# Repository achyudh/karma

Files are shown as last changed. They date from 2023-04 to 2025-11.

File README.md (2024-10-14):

# Karma

Karma is a 36-key wireless split ergonomic mechanical keyboard inspired by two very popular ergonomic keyboards: [Corne](https://github.com/foostan/crkbd) and [TOTEM](https://github.com/GEIGEIGEIST/TOTEM).

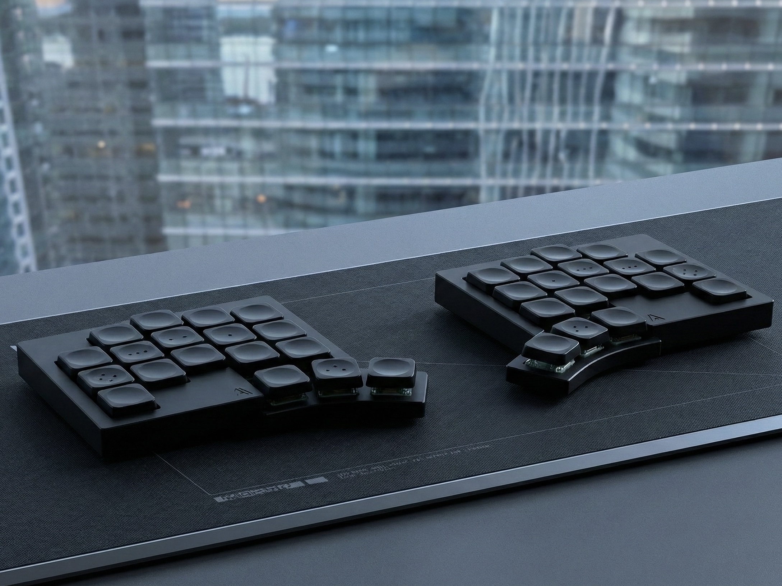
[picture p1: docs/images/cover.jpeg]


## Features

- **Ergonomic 36-key layout**: A compact layout with 3x5 column-staggered keys, plus 3 thumb keys for each side.
- **Wireless first**: Prioritizes a wireless split setup but can be used partially-wired by connecting the central side using USB-C.
- **Low-profile design**: Engineered for a sleek, low-profile build that allows your palms to rest comfortably on the table while typing. This is achieved through the use of Kailh Choc switches and recessed cutouts for hot-swap sockets, reducing the overall case height (similar to the TOTEM keyboard), and using 1mm EVA foam instead of rubber feet.
- **Exceptional battery life**: Has a battery life that is measured in weeks, not days.

### Firmware

The Karma keyboard supports the [ZMK](https://zmk.dev/) open-source firmware. You can find my ZMK configuration for this keyboard in [this repo](https://github.com/achyudh/karma-zmk).

## Build Guide

### Bill of Materials

To build the Karma keyboard, you'll need the following components:

| Part Name | Qty | Remarks |
| --- |:---:| --- |
| 2x SEEED XIAO BLE microcontrollers | 2 | |
| Kailh Choc V1 low-profile switches | 36 | Low-profile mechanical switches |
| Keycaps compatible with Kailh Choc V1 | 36 | MX-spaced keycaps are preferred for better fit |
| Hotswap sockets for Kailh Choc V1 | 36 | |
| SOD123 diodes | 36 | |
| JST PH 2-pin SMD Header | 2 | |
| 301230 LiPo Batteries | 2 | Only 1 required for partially wired build |
| 3D-printed case | 2 | |
| M2 screws (5mm length) | 8 | |
| M2 heat-set inserts (2mm height) | 8 | |
| Self-adhesive EVA foam (1mm) | - | A slimmer alternative to rubber feet |

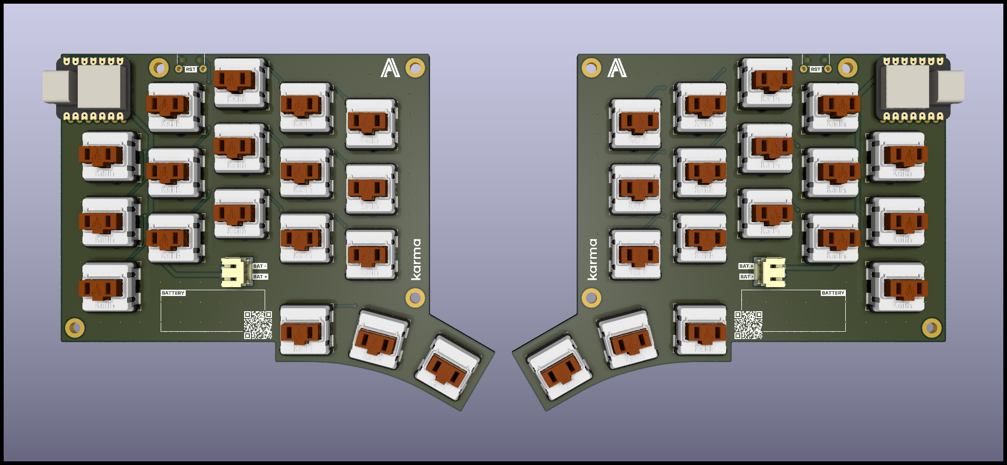
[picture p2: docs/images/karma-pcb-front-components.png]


### Assembly

**1. Order the Components**
- Zip up the gerber files for the [left side](./pcb-left/pcb-left-gerbers/) and the [right side](./pcb-right/pcb-right-gerbers/).
- Order the PCBs from a PCB prototype manufacturer like JLCPCB.
- 3D print the STL files for the case in [this repo](./enclosure/).
- All the other components are generic and can be found in Aliexpress.

**2. Solder the Diodes**
- Solder the SOD123 diodes to the top of the PCB, paying attention to the polarity.
- Apply solder to one pad, place the diode, and reflow the solder. Then solder the second pad.

**3. Install the Hotswap Sockets**
- Solder hotswap sockets in place by first securing one pad, then ensuring they are properly seated before soldering the second pad.

**4. Microcontroller Installation**
- Flash the firmware onto the SEEED XIAO BLE microcontrollers before soldering them to the PCB.
- Place the microcontroller in the designated spot and solder the pads, starting with the corners to secure it, then solder the rest.

**5. Connect the Batteries**
- Solder the JST PH 2-pin SMD Header to the PCB.
- Check the polarity of the battery with a multimeter and connect the batteries to the JST header such that the red wire is connected to the positive (+) pad and the black wire to the negative (-) pad on the PCB.

**6. Mount the Case**
- Insert M2 heat-set inserts into the screw holes in the 3D-printed case.
- Place the PCB inside the case, ensuring the microcontroller and battery fit snugly.
- Attach the two halves of the case using the M2 screws, securing them tightly.

**7. Install the Keycaps and Switches**
- Insert the Kailh Choc V1 switches into the hotswap sockets, ensuring they click into place.
- Attach your keycaps to the switches.

**8. Add EVA Foam**
- Cut and apply self-adhesive EVA foam to the bottom of the case for added grip and cushioning.

**9. Final steps**
- Once assembled, test the keyboard to ensure all switches and connections work.
- If necessary, adjust the [ZMK](https://zmk.dev/) firmware for your specific keymap.

Congratulations! You've completed your Karma keyboard build.

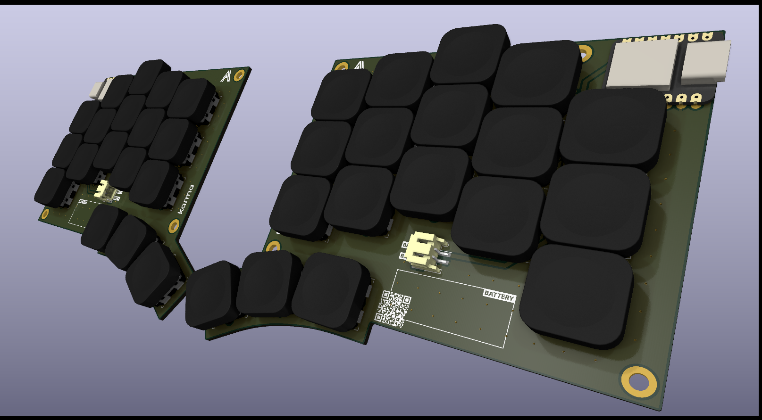
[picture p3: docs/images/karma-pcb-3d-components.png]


## License

This project is open-source and licensed under the CERN Open Hardware Licence Version 2 - Strongly Reciprocal License. See the [LICENSE](./LICENSE) file for details.

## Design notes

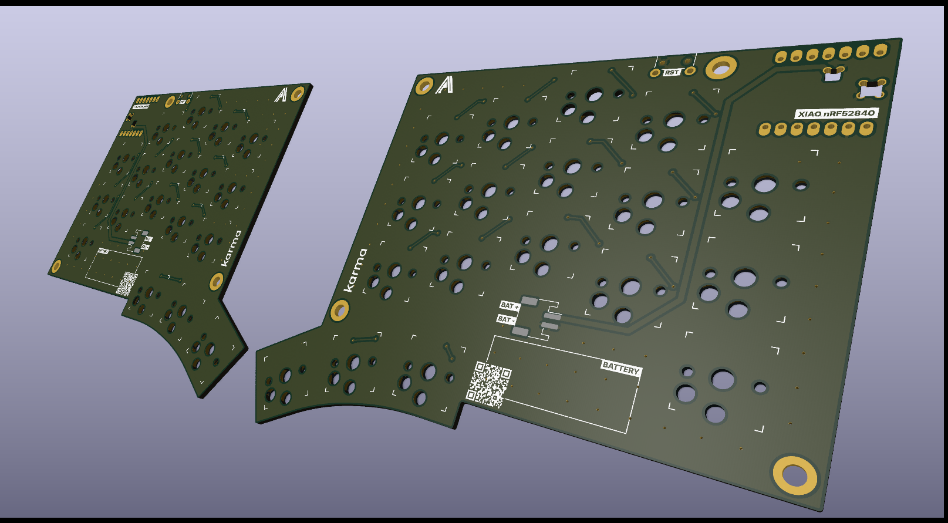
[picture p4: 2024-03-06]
docs/images/karma-pcb-3d.png

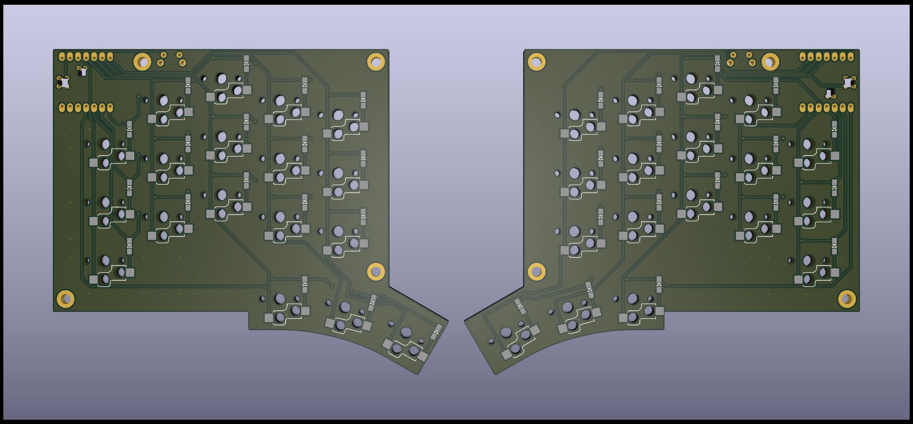
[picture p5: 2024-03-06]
docs/images/karma-pcb-back.png

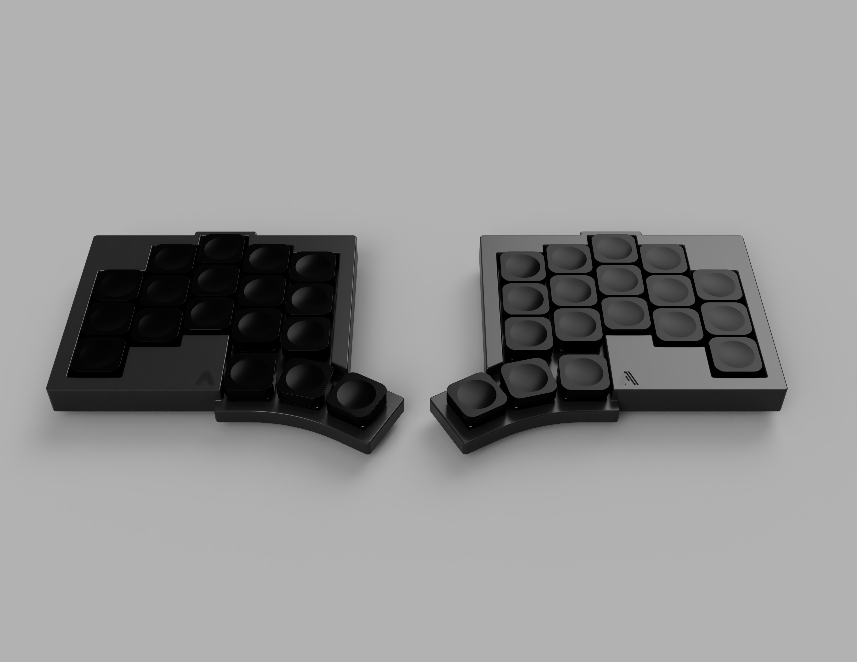
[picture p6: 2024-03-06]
docs/images/enclosure.png

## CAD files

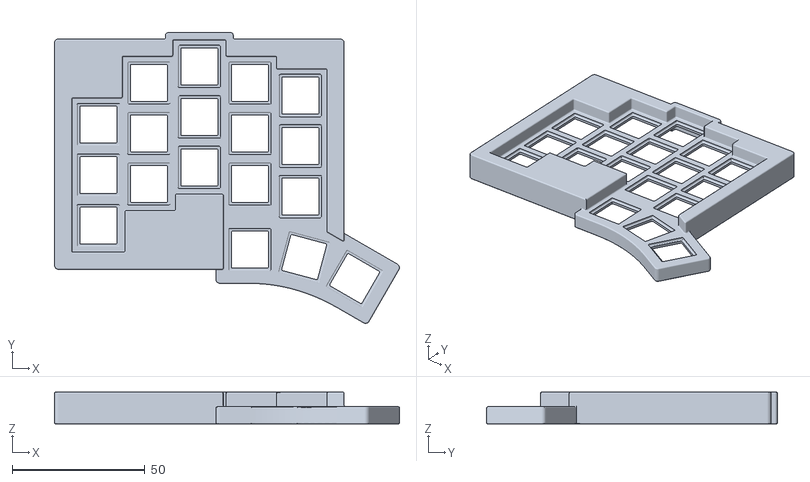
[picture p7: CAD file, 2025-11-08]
enclosure/top-left-no-logo.stl
129.8 x 109.4 x 12.0

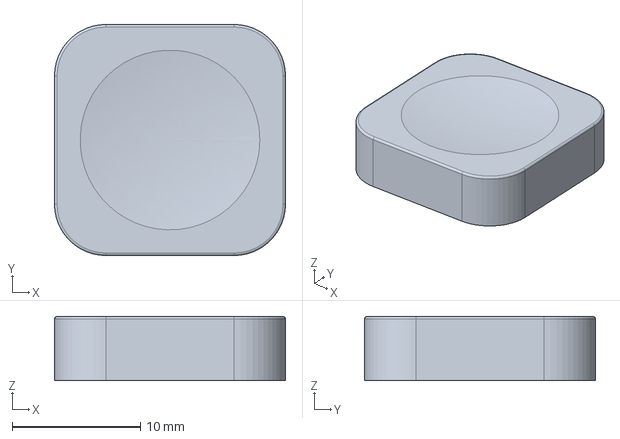
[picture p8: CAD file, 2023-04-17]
pcb-left/karmalib.step/Keycap.step
18.0 x 18.0 x 5.00 mm

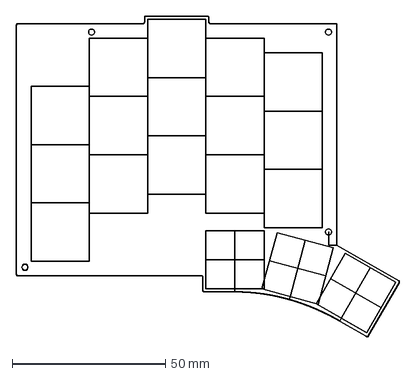
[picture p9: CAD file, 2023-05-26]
pcb-left/pcb-left-edge-cuts.dxf
124.9 x 104.5 mm

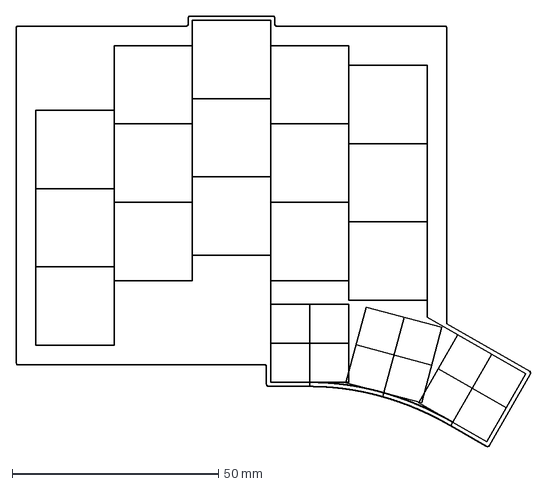
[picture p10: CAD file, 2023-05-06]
pcb-right/pcb-right-edge-cuts.dxf
124.9 x 104.5 mm

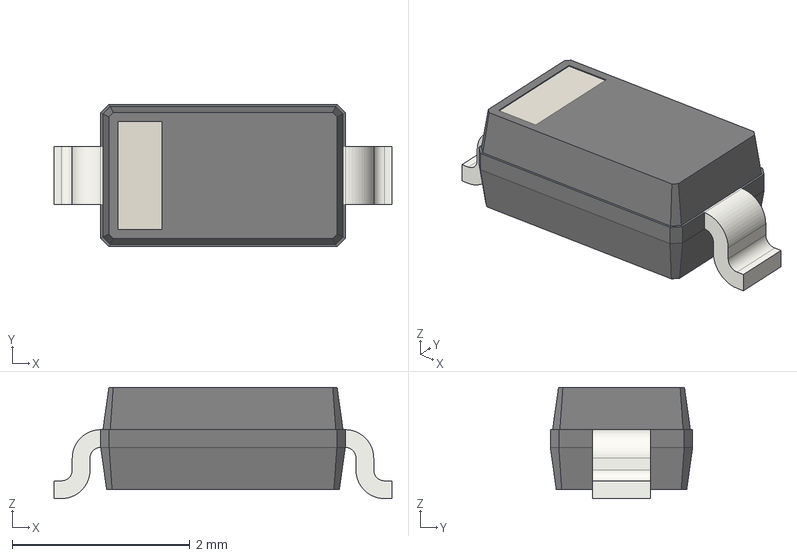
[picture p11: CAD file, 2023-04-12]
pcb-left/karmalib.step/Diode_SOD123.step
3.80 x 1.60 x 1.25 mm

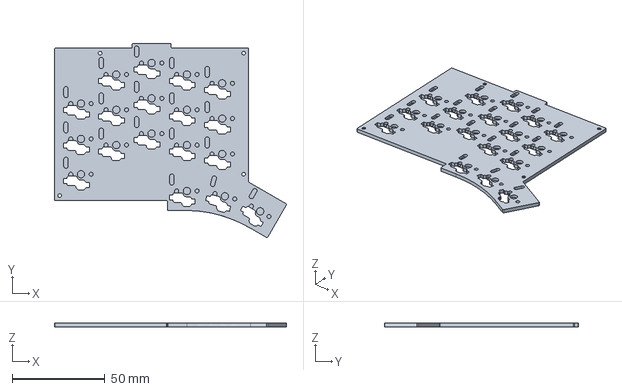
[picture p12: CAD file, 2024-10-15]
enclosure/bottom-left.step
124.8 x 104.5 x 2.00 mm

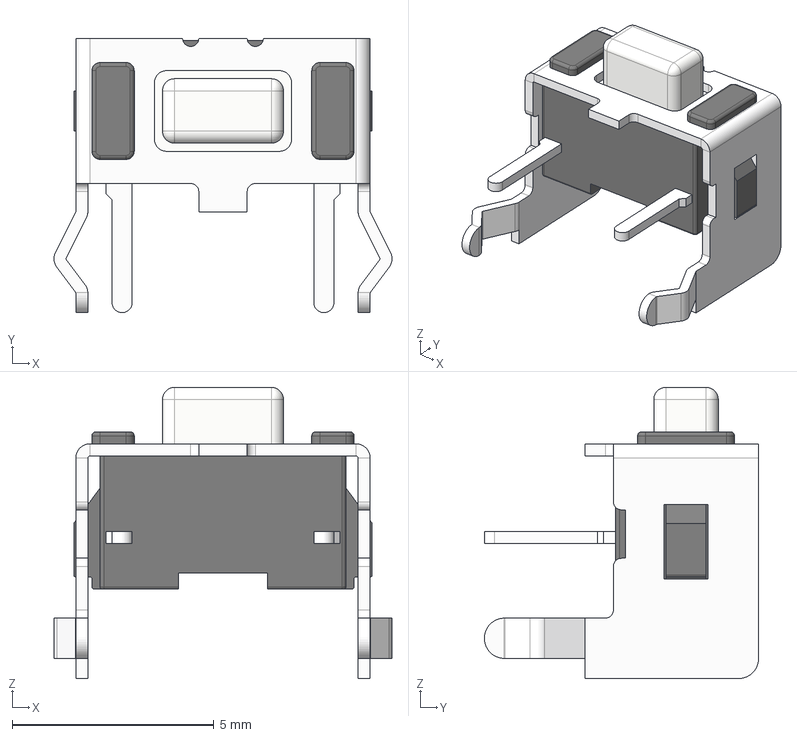
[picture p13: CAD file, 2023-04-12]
pcb-left/karmalib.step/SKHLLCA010.step
8.38 x 6.80 x 7.22 mm

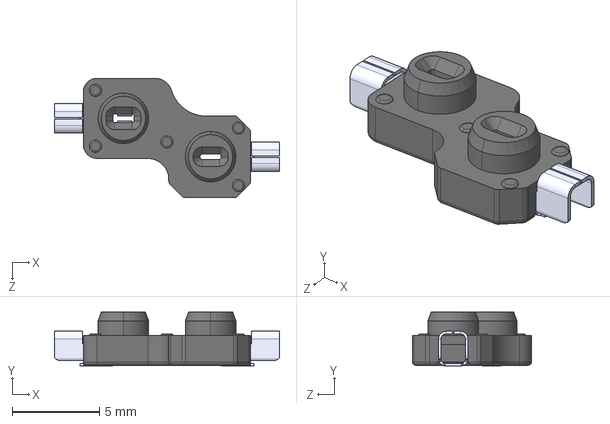
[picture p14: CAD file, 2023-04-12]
pcb-left/karmalib.step/Kailh_Socket_PG1350_Optional.step
12.9 x 3.09 x 6.85 mm
pin x 2
socket

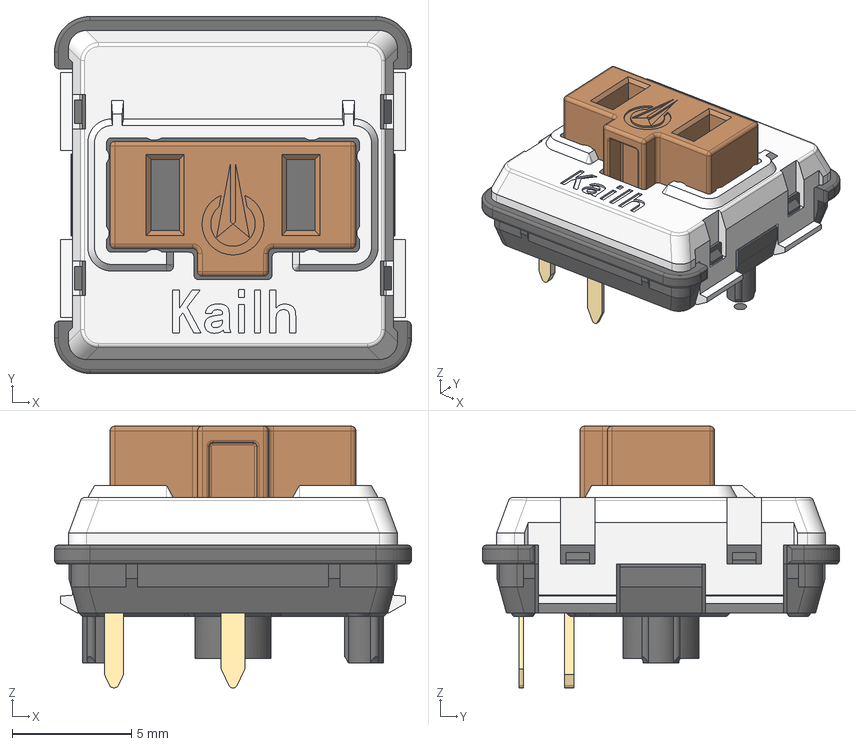
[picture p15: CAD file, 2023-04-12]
pcb-right/karmalib.step/Kailh_Switch_PG1350_Optional.step
15.0 x 15.0 x 11.0 mm

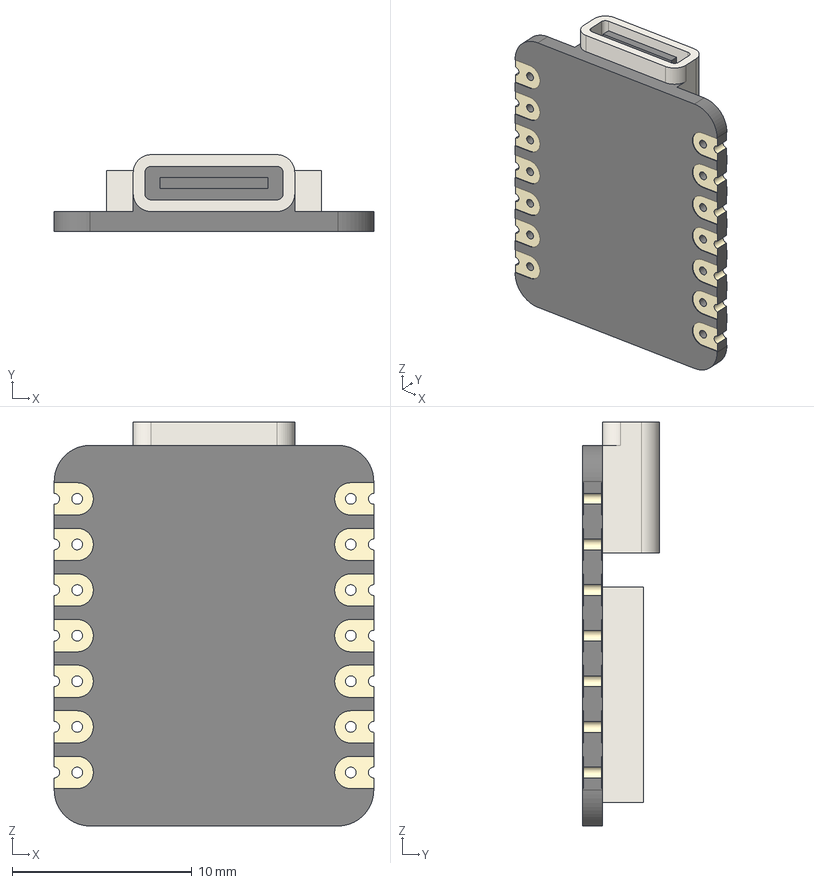
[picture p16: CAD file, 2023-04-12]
pcb-left/karmalib.step/XIAO_nRF52840.step
17.8 x 4.27 x 22.5 mm

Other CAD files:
enclosure/top-right-no-logo.stl
enclosure/top-left.step
enclosure/bottom-right.step
enclosure/top-right.step
enclosure/bottom-left.stl
enclosure/bottom-right.stl
enclosure/top-left.stl
enclosure/top-right.stl

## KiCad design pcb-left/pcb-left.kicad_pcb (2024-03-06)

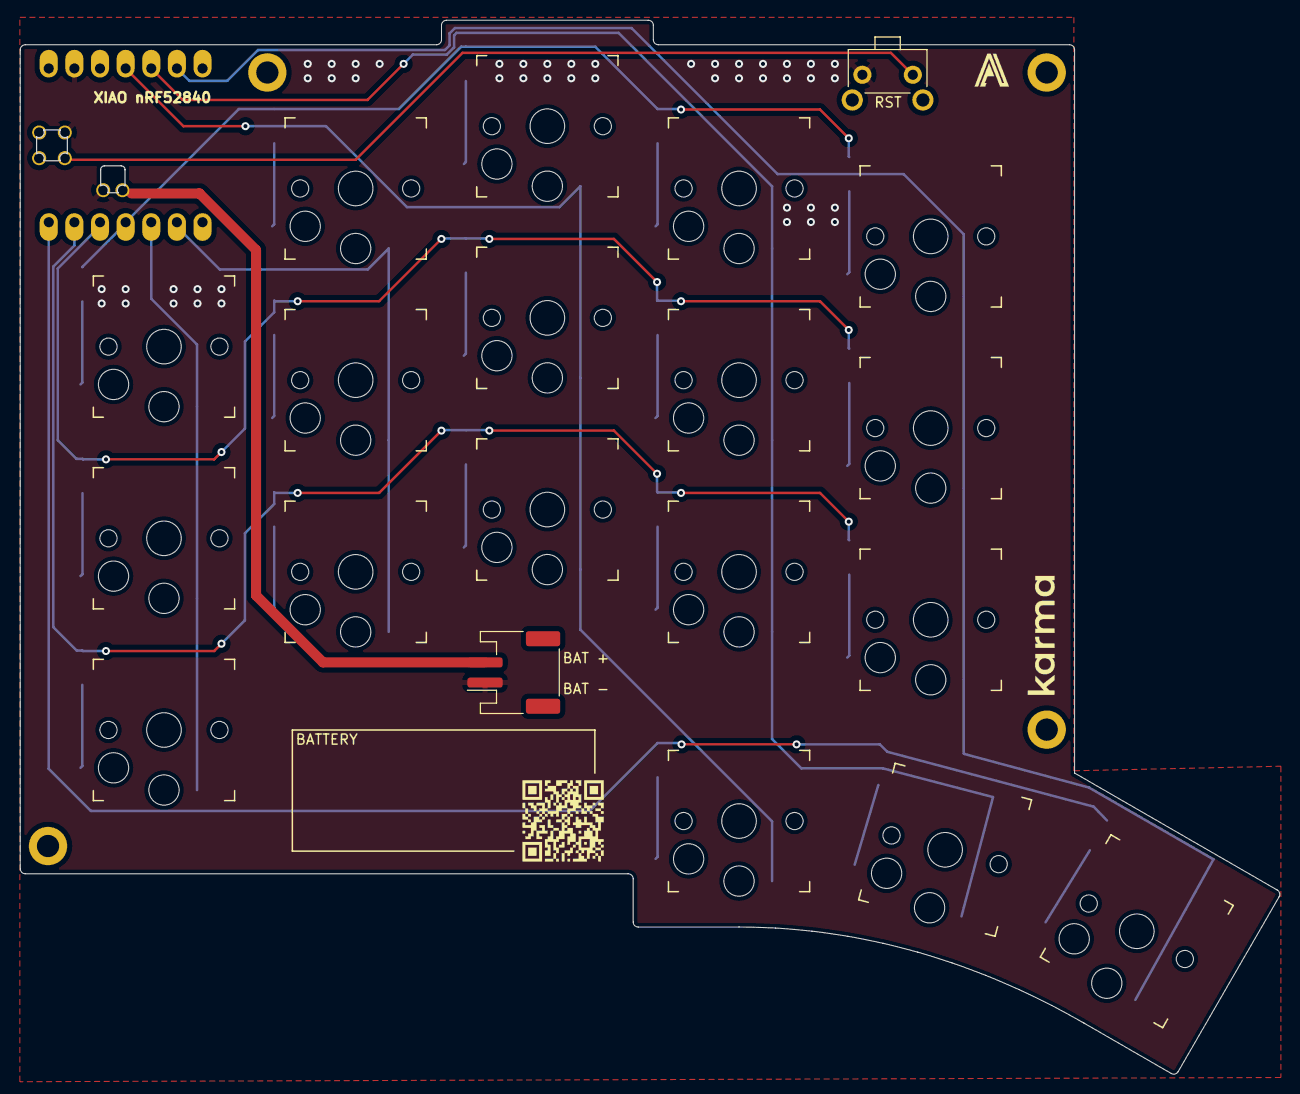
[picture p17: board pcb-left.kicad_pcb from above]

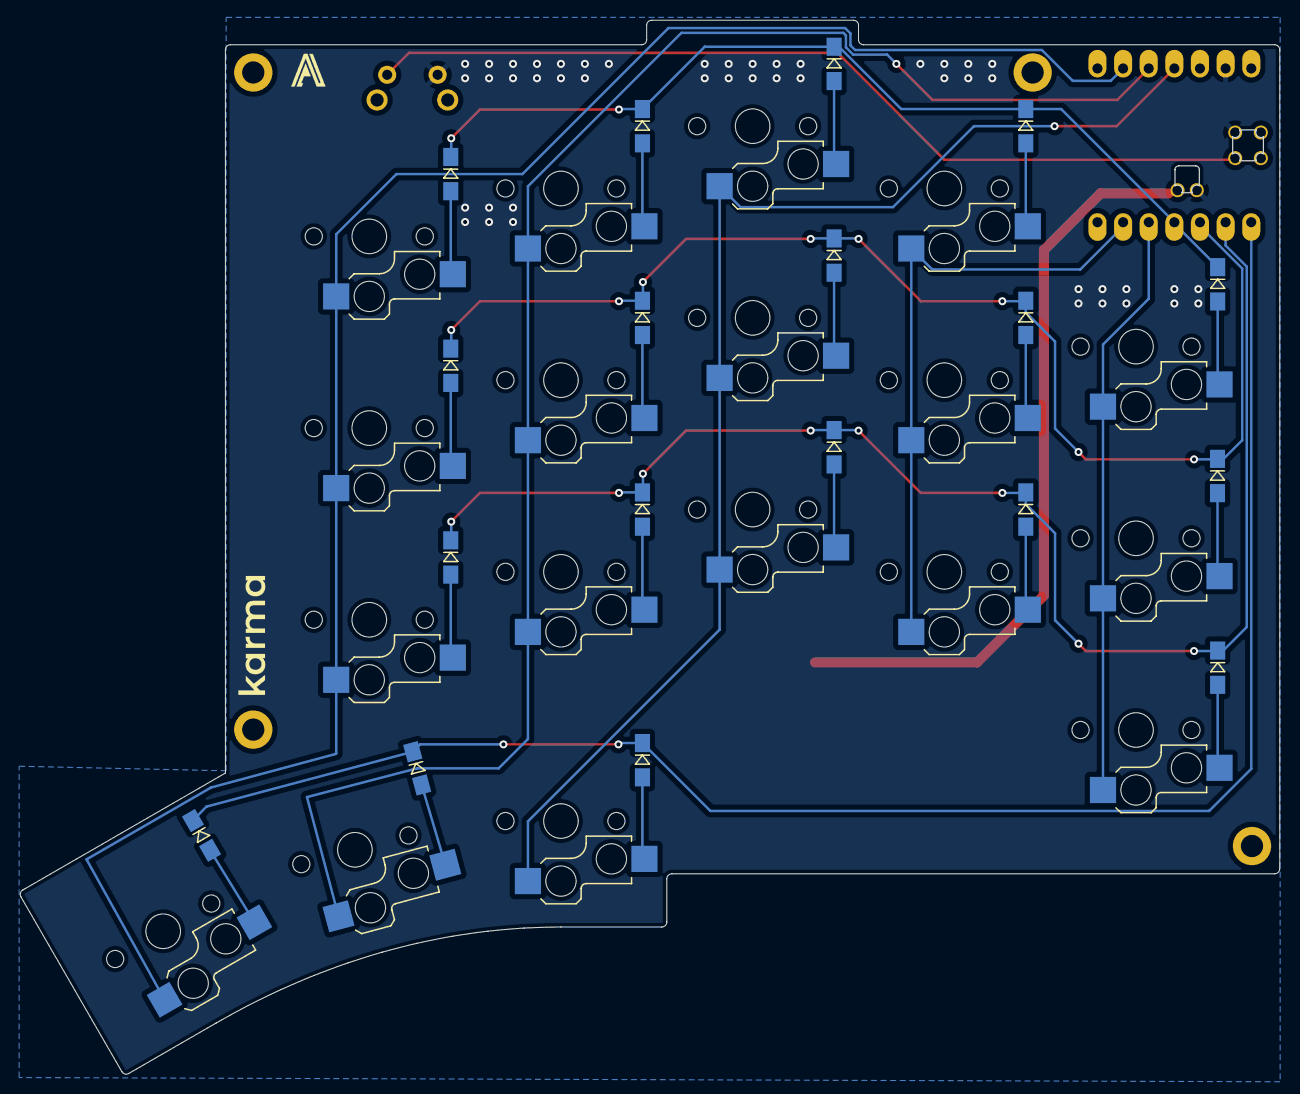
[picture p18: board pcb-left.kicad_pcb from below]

Board: 2 copper layers, 124.8 x 104.5 mm, 39 parts (18 on the bottom side), 30 nets.

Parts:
DL1, DL2, DL3, DL4, DL5, DL6, DL7, DL8, DL9, DL10, DL11, DL12, DL13, DL14, DL15, DL16, DL17, DL18: D_Small; Diode_SOD123
J1: BAT; JST_PH_S2B-PH-SM4-TB_1x02-1MP_P2.00mm_Horizontal
RSW1: SW_Push; SKHLLCA010
SWL1, SWL2, SWL3, SWL4, SWL5, SWL6, SWL7, SWL8, SWL9, SWL10, SWL11, SWL12, SWL13, SWL14, SWL15, SWL16, SWL17, SWL18: SW_Push_45deg; Kailh_Socket_PG1350_Optional
U1: xiao-ble; XIAO_nRF52840_SMD_Cutout

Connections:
COL0_L: SWL1.1, SWL6.1, SWL11.1, U1.5 (A8_SDA/0.04_H)
COL1_L: SWL2.1, SWL7.1, SWL12.1, U1.6 (A9_SCL/0.05_H)
COL2_L: SWL3.1, SWL8.1, SWL13.1, SWL16.1, U1.11 (A6_MOSI/1.15)
COL3_L: SWL4.1, SWL9.1, SWL14.1, SWL17.1, U1.10 (A5_MISO/1.14)
COL4_L: SWL5.1, SWL10.1, SWL15.1, SWL18.1, U1.9 (A7_SCK/1.13)
GND_L: J1.1, RSW1.2, U1.13 (GND), U1.18 (GND), U1.20 (GND)
unnamed: DL1.2 (A), SWL1.2
unnamed: DL2.2 (A), SWL2.2
unnamed: DL3.2 (A), SWL3.2
unnamed: DL4.2 (A), SWL4.2
unnamed: DL5.2 (A), SWL5.2
unnamed: DL6.2 (A), SWL6.2
unnamed: DL7.2 (A), SWL7.2
unnamed: DL8.2 (A), SWL8.2
unnamed: DL9.2 (A), SWL9.2
unnamed: DL10.2 (A), SWL10.2
unnamed: DL11.2 (A), SWL11.2
unnamed: DL12.2 (A), SWL12.2
unnamed: DL13.2 (A), SWL13.2
unnamed: DL14.2 (A), SWL14.2
unnamed: DL15.2 (A), SWL15.2
unnamed: DL16.2 (A), SWL16.2
unnamed: DL17.2 (A), SWL17.2
unnamed: DL18.2 (A), SWL18.2
RESET_L: RSW1.1, U1.17 (RESET)
ROW0_L: DL1.1 (K), DL2.1 (K), DL3.1 (K), DL4.1 (K), DL5.1 (K), U1.4 (A11/0.29)
ROW1_L: DL6.1 (K), DL7.1 (K), DL8.1 (K), DL9.1 (K), DL10.1 (K), U1.3 (A10/0.28)
ROW2_L: DL11.1 (K), DL12.1 (K), DL13.1 (K), DL14.1 (K), DL15.1 (K), U1.2 (A4/0.03_H)
ROW3_L: DL16.1 (K), DL17.1 (K), DL18.1 (K), U1.1 (A2/0.02_H)
VBAT_L: J1.2, U1.19 (BAT)

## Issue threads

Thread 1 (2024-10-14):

Missing rest button hole on case?

tangbonze, 2024-10-14:
I can't find reset switch hole on case. Could you please check if you miss it?

I mod a bit to enable choc v2 switch but I also need to change hole in bottom case. Could you please kindly share bottom case step? That will make it more easy to mod.

Thanks.

achyudh, 2024-10-15:
> I can't find reset switch hole on case. Could you please check if you miss it?

This is actually intentional. I didn't see the need for making a reset switch as there were a bunch of other options:
- Pressing the reset button on the XIAO BLE microcontroller
- Shorting the reset pads on the PCB
- Mapping a key combination to reset in ZMK (this is what I normally use for flashing)

> Could you please kindly share bottom case step?

 Happy to share the step files! They have been added to https://github.com/achyudh/karma/tree/main/enclosure

tangbonze, 2024-10-15:
Thank you and great design!
________________________________
发件人: Achyudh Ram ***@***.***>
发送时间: 2024年10月15日 9:56
收件人: achyudh/karma ***@***.***>
抄送: KeebNERD ***@***.***>; Author ***@***.***>
主题: Re: [achyudh/karma] Missing rest button hole on case? (Issue #1)

I can't find reset switch hole on case. Could you please check if you miss it?

This is actually intentional. I didn't see the need for making a reset switch as there were a bunch of other options:

  *   Pressing the reset button on the XIAO BLE microcontroller
  *   Shorting the reset pads on the PCB
  *   Mapping a key combination to reset in ZMK (this is what I normally use for flashing)

Could you please kindly share bottom case step?

Happy to share the step files! They have been added to https://github.com/achyudh/karma/tree/main/enclosure

―
Reply to this email directly, view it on GitHub<https://github.com/achyudh/karma/issues/1#issuecomment-2412655214>, or unsubscribe<https://github.com/notifications/unsubscribe-auth/ATFVAGKHB7IDZCX53OUK4SDZ3RY3TAVCNFSM6AAAAABP4T6ZWKVHI2DSMVQWIX3LMV43OSLTON2WKQ3PNVWWK3TUHMZDIMJSGY2TKMRRGQ>.
You are receiving this because you authored the thread.Message ID: ***@***.***>

Closed 2024-10-15.

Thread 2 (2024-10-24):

6 column version?

KraXen72, 2024-10-24:
please?
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

achyudh, 2024-11-13:
I sadly don't have the time to make a 6 column version but the KiCad files for the PCB and the Step files for the case are in the repo if someone else wants to give it a shot.

Closed 2025-05-14.

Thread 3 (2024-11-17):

BoM is missing the reset buttons

allymparker, 2024-11-17:
From the Kicad files it looks like they should be Alps SKHLLCA010 3 * 6 * 3.5mm?

EG: https://www.aliexpress.com/item/1005007369566828.html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

achyudh, 2025-01-26:
Alps SKHLLCA010 does seem correct but I did not use a reset button in my build and the case does not have a cutout for that. I mostly created one for flashing the firmware before assembly (you could alternatively use the reset button on the XIAO for this). I also added mappings in ZMK for reset and to enter the bootloader, pretty much negating the need for a reset button: https://zmk.dev/docs/keymaps/behaviors/reset

Closed 2025-08-09.

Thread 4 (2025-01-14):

No Power button?

ev1lb0ygen1us, 2025-01-14:
Why is there no power button?

achyudh, 2025-01-26:
I skipped adding a power button in favor of just using the ZMK deep sleep functionality to save power when the keyboard is not in use. Seems to be working pretty well for me so far.

Closed 2025-08-09.

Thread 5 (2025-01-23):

Controller sockets

UnEmotioneD, 2025-01-23:
What kind of socket or method you used to solder the controller to the PCB?

 After using the how swap socket such as this  (https://typeractive.xyz/products/ez-machine-sockets-and-headers) the controller was to high to fit in the case and the female socket protruding through the bottom of the pcb made the bottom case to not seat flat.

UnEmotioneD, 2025-01-26:
Looks like I should just solder the controller directly to the PCB without any use of sockets

achyudh, 2025-01-26:
Sorry for the delayed response, yes you are correct. I did not use any sockets. If you need to use sockets, the height of the keyboard will need to be increased, along with the USB cutout, to accommodate them.

Closed 2025-01-26.

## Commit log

2023-04-05 Add karma schema rev 0.1
    [karma-pcb.kicad_pcb, karma-pcb.kicad_sch]
2023-04-08 Add left side pcb design rev 0.1
    [karma-pcb.kicad_pcb]
2023-04-11 Fix board edge DRC failures on the left side
    [karma-pcb.kicad_pcb]
2023-04-11 Fix board edge DRC failures on the right side
    [karma-pcb.kicad_pcb]
2023-04-11 Fix positioning of the controller on the right pcb
    [karma-pcb.kicad_pcb]
2023-04-12 Improve trace routing
    [karma-pcb.kicad_pcb]
2023-04-12 Add 3D models to karmalib.pretty
    [Diode_SOD123.step, Kailh_Socket_PG1350_Optional.step, Kailh_Switch_PG1350_Optional.step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]
2023-04-14 Update Kailh PG1350 footprint to be hotswap only
2023-04-14 Update schema to rev 0.2
    [karma-pcb.kicad_sch]
2023-04-14 Update PCB layout to rev 0.2
    [karma-pcb.kicad_pcb]
2023-04-14 Add via stitching
    [karma-pcb.kicad_pcb]
2023-04-15 Add silkscreen labels
    [karma-pcb.kicad_pcb]
2023-04-15 Add silkscreen label for controller
    [karma-pcb.kicad_pcb]
2023-04-17 Add 3D model for keycaps
    [Keycap.step, karma-pcb.kicad_pcb]
2023-05-06 Update left PCB layout to rev 0.3
    [karma-pcb-edges.dxf, karma-pcb.kicad_pcb]
2023-05-08 Split karma-pcb into pcb-left and pcb-right
    [Diode_SOD123.step, Kailh_Socket_PG1350_Optional.step, Kailh_Switch_PG1350_Optional.step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]
2023-05-11 Align mounting holes in left-pcb
    [karma-pcb-edges.dxf, left-pcb-edge-cuts.dxf, left-pcb.kicad_pcb]
2023-05-26 Update right-pcb to rev 0.3
    [right-pcb.kicad_pcb]
2023-05-26 Fix DRC issues in left-pcb
    [left-pcb-edge-cuts.dxf, left-pcb.kicad_pcb]
2023-05-26 Fix DRC issues in right-pcb
    [right-pcb.kicad_pcb]
2023-05-26 Update 3d models for right-pcb
    [right-pcb.kicad_pcb]
2023-05-26 Update right-pcb schema to rev 0.3
    [right-pcb.kicad_sch]
2023-05-27 Update step models for left-pcb and right-pcb
2023-05-27 Add enclosure stl files
    [Bottom Left.stl, Bottom Right.stl, Keybed Left.stl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]
2023-05-28 Rename project directories
    [Bottom Right.stl, Diode_SOD123.step, Kailh_Socket_PG1350_Optional.step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]
2023-05-28 Remove compressed gerber files
2023-06-19 Fix microcontroller placement
    [pcb-left.kicad_pcb, pcb-right.kicad_pcb]
2023-07-14 Update enclosure to rev 0.2
    [bottom-left.stl, bottom-right.stl, keybed-left.stl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]
2024-03-06 Update schematic and pcb to rev 0.32
    [pcb-left-B_Cu.gbr, pcb-left-B_Mask.gbr, pcb-left-B_Paste.gbr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]
2024-03-06 Add pcb and enclosure images for documentation
2024-03-06 Add pcb schematics for documentation
2024-10-15 enclosure: Add step files
    [bottom-left.step, bottom-right.step, top-left.step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]
2025-11-08 enclosure: add no-logo variants
    [top-left-no-logo.stl, top-right-no-logo.stl]
